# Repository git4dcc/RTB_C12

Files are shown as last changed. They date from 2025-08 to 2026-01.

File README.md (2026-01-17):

# RTB_C12





My homebrew RTB C12 Micro Booster implements a booster, DCC generator and Real-time Railcom detector. The booster is optimized for N-scale in respect to track voltage and current.

<details>
<summary>See also</summary>

- [RTB_C10 - Master](https://github.com/git4dcc/RTB_C10)
- [RTB_C11 - Power](https://github.com/git4dcc/RTB_C11)
- [RTB_C13 - Track Sensor](https://github.com/git4dcc/RTB_C13)
- [RTB_P15 - Base](https://github.com/git4dcc/RTB_P15)

</details>

<details>
<summary>User Guides</summary>

- User Guide - DE
- [User Guide - EN](https://rtb4dcc.de/rtb_user_guide_en/)

</details>

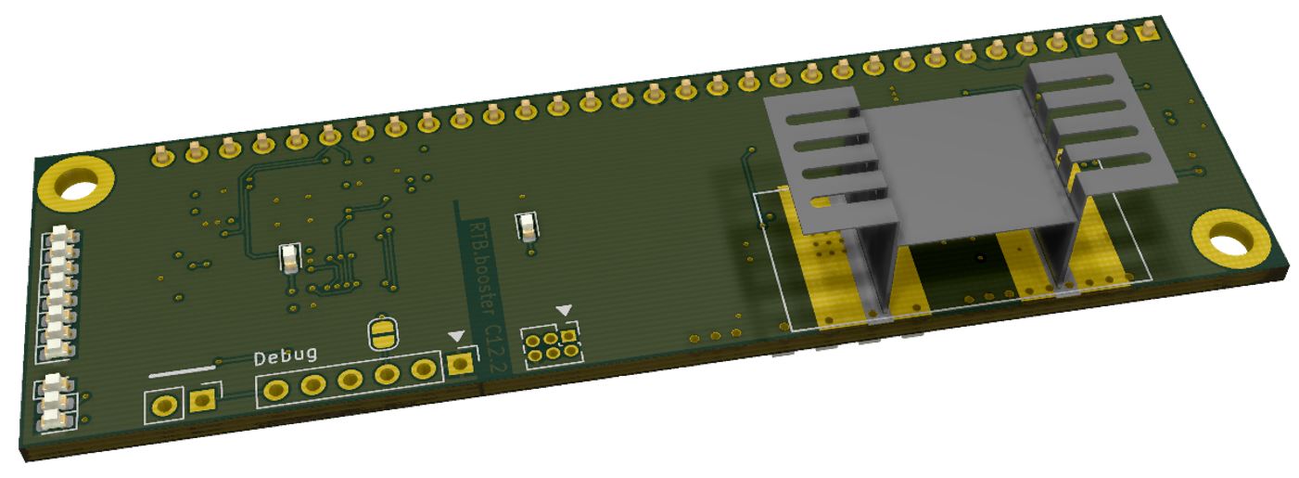
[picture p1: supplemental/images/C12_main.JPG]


## Booster features
- **FDX**
  - FDX bus (2Mbps full duplex)
- **DCC protocol generator**
  - unlimited decoder stack depth
  - DCC bandwidth monitor
  - DCC-A protocol (incl. stretched start bit)
  - DCC-R protocol (incl. update of RTB decoder on main)
- **MDU protocol generator**
  - Zimo MDU ([Multi Decoder Update](https://github.com/ZIMO-Elektronik/MDU))
  - update of MS and MN decoder
  - can update multiple MN/MS decoder concurrently
- **DECUP protocol generator**
  - Zimo DECUP ([**Dec**oder **Up**date](https://github.com/ZIMO-Elektronik/DECUP))
  - update of MX decoder
- **Booster**
  - Software programmable output voltage (3..18V)
  - 1A continuous current (1.5A peak)
  - Current limiter
  - Short circuit detection
  - Configurable bridge dead time (170ns..3500ns)
  - DCC signal timing adjustable [micro sec granularity]
  - Railcom Cutout timing adjustable
  - Up to 500kHz fast signaling
  - Voltage and current measurement
- **Railcom Detector**
  - channel 1 / channel 2
  - detects unlimited number of decoder
  - Railcom polarity detection
  - Railcom timing capture for decoder analysis
- **Service Mode**
  - read/write DCC decoder in “service mode”
  - ACK current detector adjustable
- **Firmware update over the bus**

# Hardware
The PCB layout uses SMD footprints with 0.4mm pitch and mostly 0603 parts. Reflow soldering is recommended, but with some experience handsoldering is also possible.
Further, the PCB has been optimized for automated assembly (BOM and Position files as CSV).

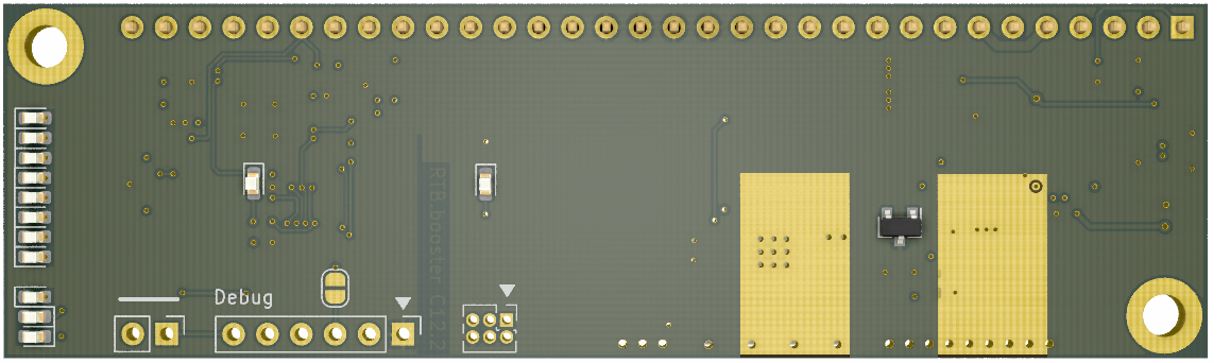
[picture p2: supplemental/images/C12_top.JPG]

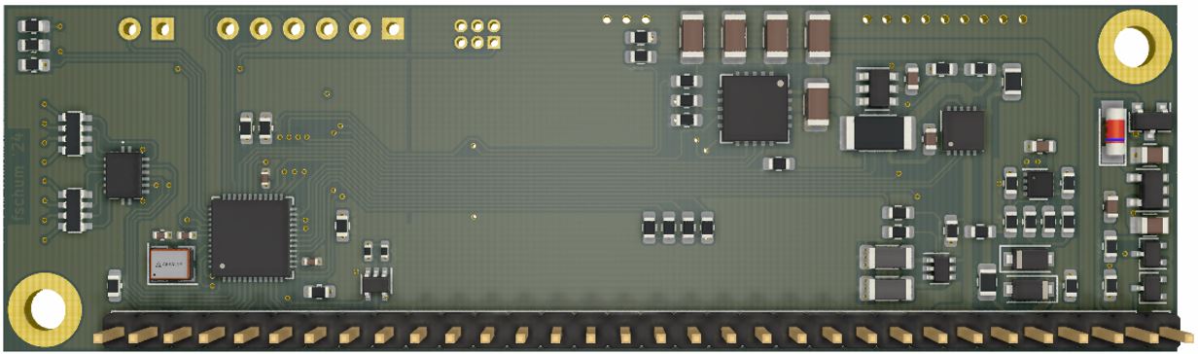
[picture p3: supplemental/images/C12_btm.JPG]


## PCB
- 4-layer PCB, FR4, 1.6mm
- CPU: AVR64DB48
- H-Bridge: BD63573NUV
- Voltage: OPA521

## Kicad
[Schematic](doc/C12_schematic.pdf) | [Layout](doc/C12_layout.pdf) | [Gerber](gerber)

# Firmware
Filename structure: { **pcb** }{ **code** }{ **version** }.hex

Example: **C12F0001**.hex

| | Description |
| --- | --- |
| **pcb** | Name of matching hardware (**C12**) |
| **code** | Type of code contained (**R**=rom, **B**=bootloader, **F**=flash, **U**=bld update, **P**=UPDI factory code) |
| **version** | Release version (**####**) |

[Firmware files](firmware)

## UPDI / Fuses
The fuse settings as well as the P-code (C12Pxxxx.hex) has to be installed by using UPDI.<br>

| Fuses Setting |
| --- |
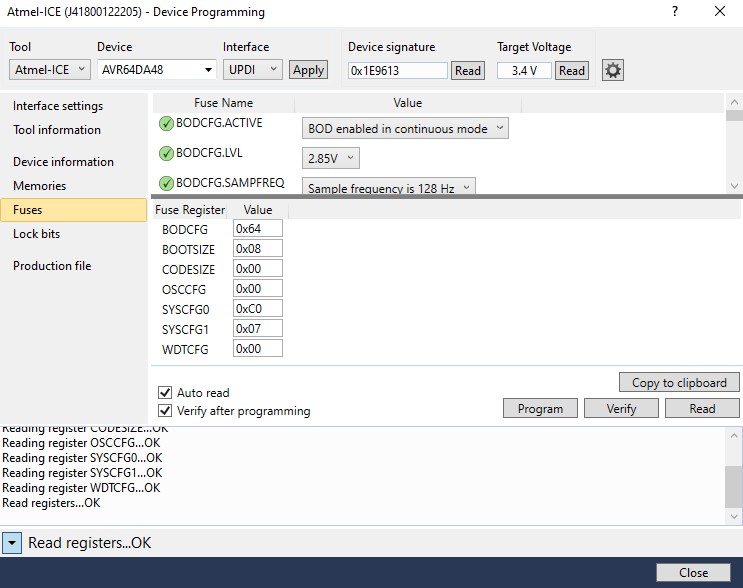
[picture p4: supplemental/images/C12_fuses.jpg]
||

# Images
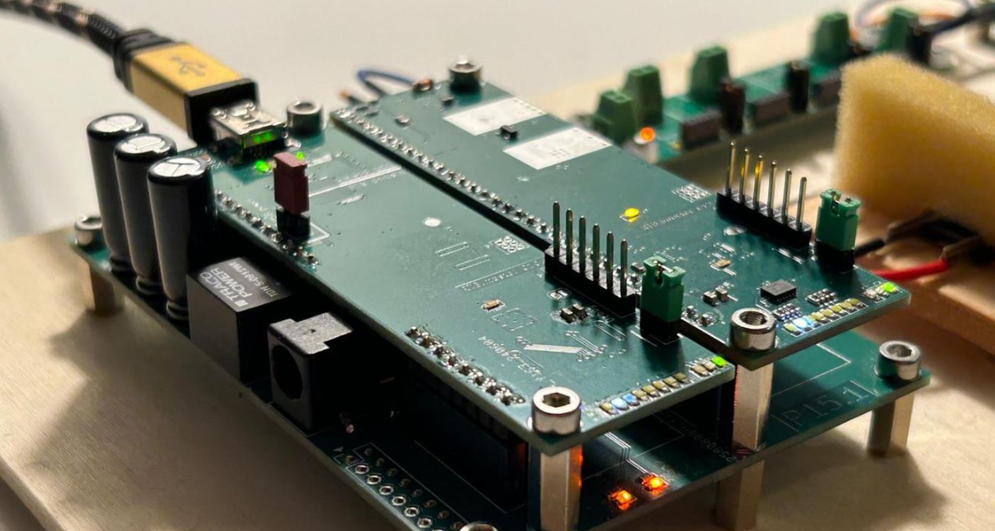
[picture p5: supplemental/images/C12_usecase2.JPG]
 

# YouTube
See the C12 booster in action.<br><br>
[](https://youtu.be/n1b2I9GNrNY)

This project is intended for hobby use only and is distributed in accordance with the Apache License 2.0 agreement.

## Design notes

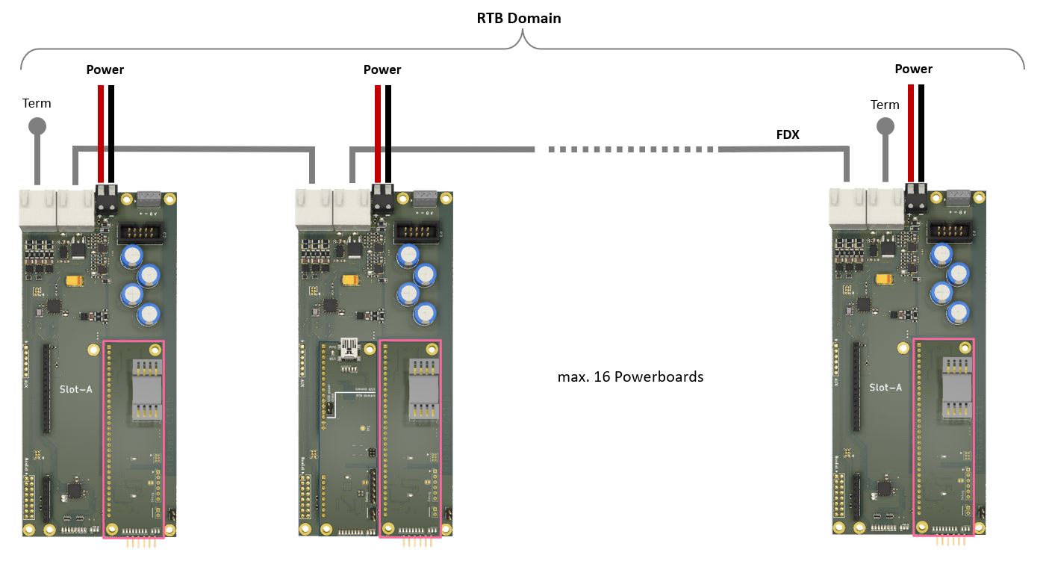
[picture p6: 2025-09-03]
supplemental/images/C12_usecase3.JPG

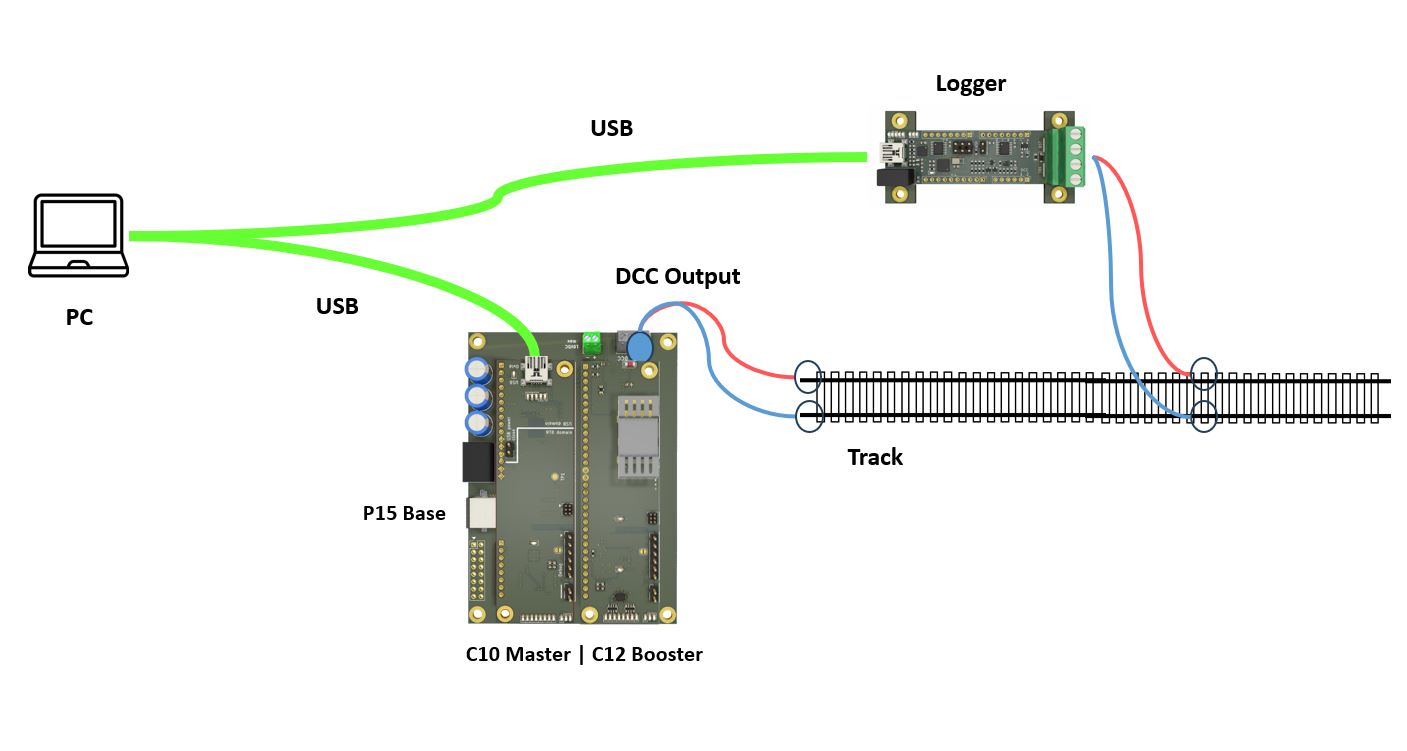
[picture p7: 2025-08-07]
supplemental/images/C12_usecase1.JPG

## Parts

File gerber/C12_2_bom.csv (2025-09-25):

Designator | Footprint | Quantity | Value | LCSC Part #
C1, C19, C4, C8, C9 | 1206 | 5 | 22uF | C12891
C10, C14, C15, C6 | 0402 | 4 | 100nF | C307331
C11, C20 | 0603 | 2 | 100nF | C14663
C2, C3 | 0805 | 2 | 10uF | C440198
C21, C5 | 0603 | 2 | 1uF | C15849
D12 | 0603 | 1 | Reset(red) | C2986060
D13 | 0603 | 1 | Msg(blu) | C434421
D14, D32, D33, D34, D35, D36, D37 | 0603 | 7 | LED_Small | C2290
D16 | 0603 | 1 | LED | C84264
D17 | D_MiniMELF | 1 | D_Schottky_Small | C81181
D3, D4 | SOT-323_SC-70 | 2 | BAT54S | C549280
D31 | SOT-323_SC-70 | 1 | BAT54C | C82467
D38 | 0603 | 1 | LED(wht) | C2290
D5 | 0603 | 1 | Hbt(grn) | C84264
D6, D9 | D_SOD-123F | 2 | SS34FA | C719833
D8 | 0603 | 1 | LED | C72038
H1, H3 | MountingHole_3.2mm_M3_ISO7380_Pad | 2 | MountingHole
IC1 | VSON-10-1EP_3x3mm_P0.5mm_EP1.2x2mm | 1 | BD63573NUV-E2 | C2150564
IC3 | DHVQFN-16-1EP_2.5x3.5mm_P0.5mm_EP1x2mm | 1 | 74HC595BQ,115 | C547123
J1 | PinHeader_1x06_P2.54mm_Vertical | 1 | Debug IF
J2 | PinHeader_1x32_P2.54mm_Vertical | 1 | Slot Connector
J3 | PinHeader_2x03_P1.27mm_Vertical | 1 | UPDI
JP1 | PinHeader_1x02_P2.54mm_Vertical | 1 | Jumper_2_Open
JP2 | SolderJumper-2_P1.3mm_Open_RoundedPad1.0x1.5mm | 1 | SolderJumper_2_Open
Q1 | SOT-363_SC-70-6 | 1 | BC847BDW1 | C82368
R1, R19 | 0402 | 2 | 3.3k | C25890
R10 | 0603 | 1 | 56k | C23206
R11 | 0603 | 1 | 33k | C4216
R12, R35 | 0603 | 2 | 10k | C25804
R13, R18, R27 | 0603 | 3 | 220k | C22961
R14, R21, R23 | 0603 | 3 | 9.1k | C23260
R17 | 2010 | 1 | 0.025 | C22470461
R2, R22 | 0603 | 2 | 100k | C25803
R20 | 0603 | 1 | 100 | C22775
R24, R25, R28, R30, R39 | 0603 | 5 | 3.3k | C22978
R26, R32 | 1206 | 2 | 300 | C17887
R29 | 0603 | 1 | 4.7k | C23162
R3, R33, R34, R4, R5, R6 | 0603 | 6 | 1k | C21190
R31 | 0805 | 1 | 10k | C17414
R36, R37, R38 | 0603 | 3 | 22k | C31850
R7, R8 | 0603 | 2 | 82k | C23254
R9 | 0805 | 1 | 22 | C17561
RN3, RN4 | R_Array_Convex_4x0603 | 2 | 4.7k | C1980
U1 | SOT-353_SC-70-5 | 1 | 74AHC1G08 | C12490
U15 | SOT-23 | 1 | MCP9700AT-ETT | C127949
U3 | SOT-23-6 | 1 | INA181A1 | C2058943
U4 | DFN-8-1EP_NG_2x2mm_Pitch0.5mm | 1 | LM393 | C2970927
U5 | SOT-23-5 | 1 | MIC5235-3.3 | C89886
U6 | QFN-48-1EP_6x6mm_P0.4mm_EP4.2x4.2mm | 1 | AVR64DA48 | C3227399
U8 | QFN-20-1EP_5x5mm_P0.65mm_EP3.35x3.35mm | 1 | OPA521 | C2058423
X1 | Oscillator_SMD_Abracon_ASE-4Pin_3.2x2.5mm | 1 | ASE-24MHz | C1987527

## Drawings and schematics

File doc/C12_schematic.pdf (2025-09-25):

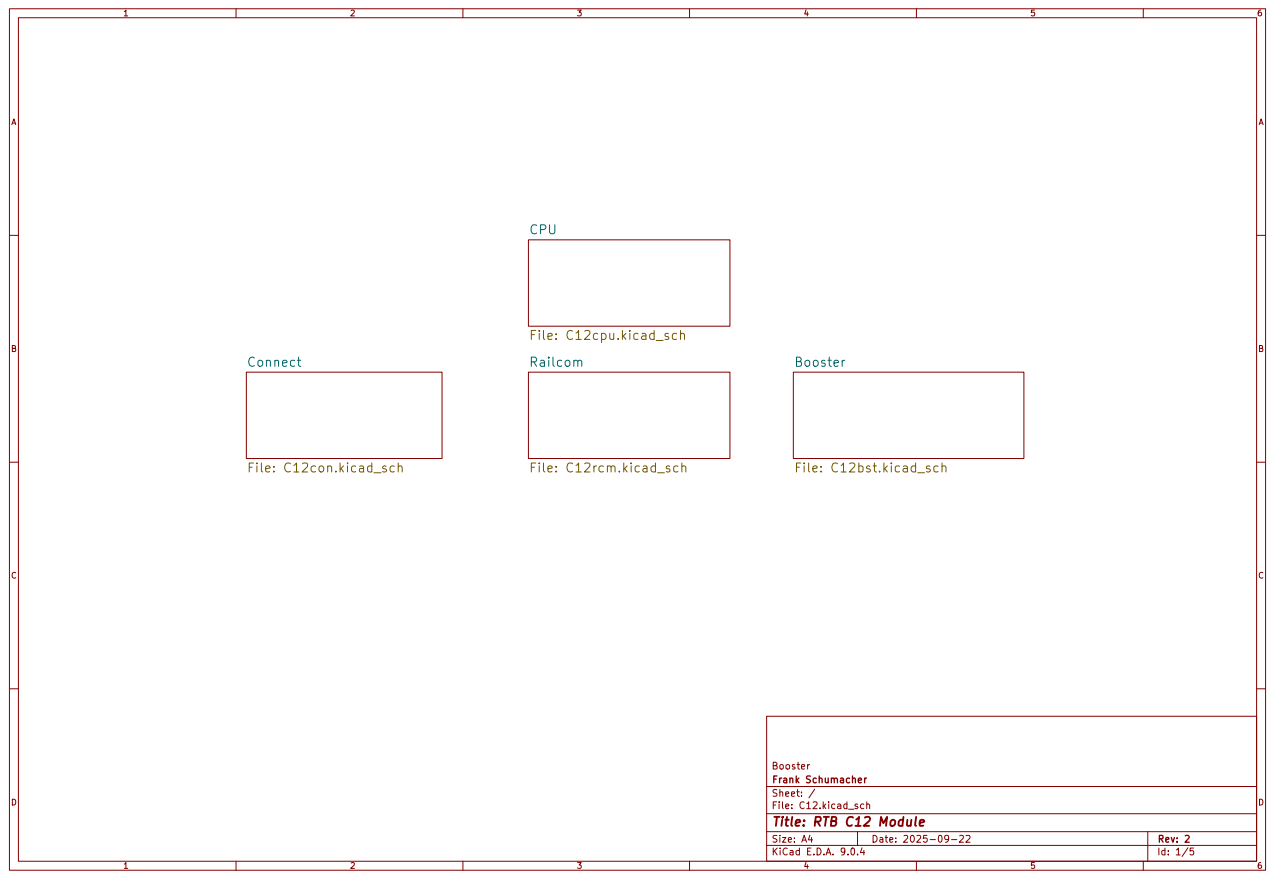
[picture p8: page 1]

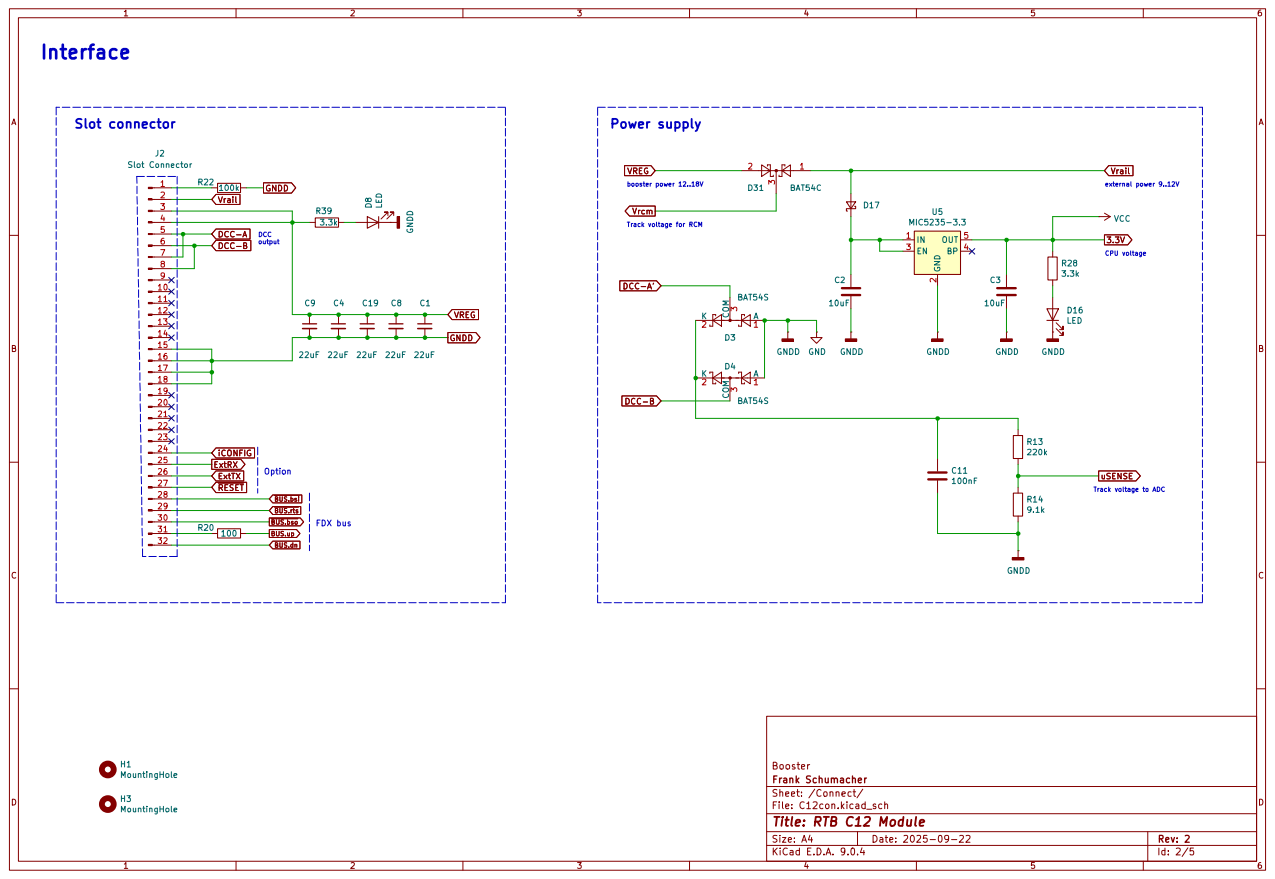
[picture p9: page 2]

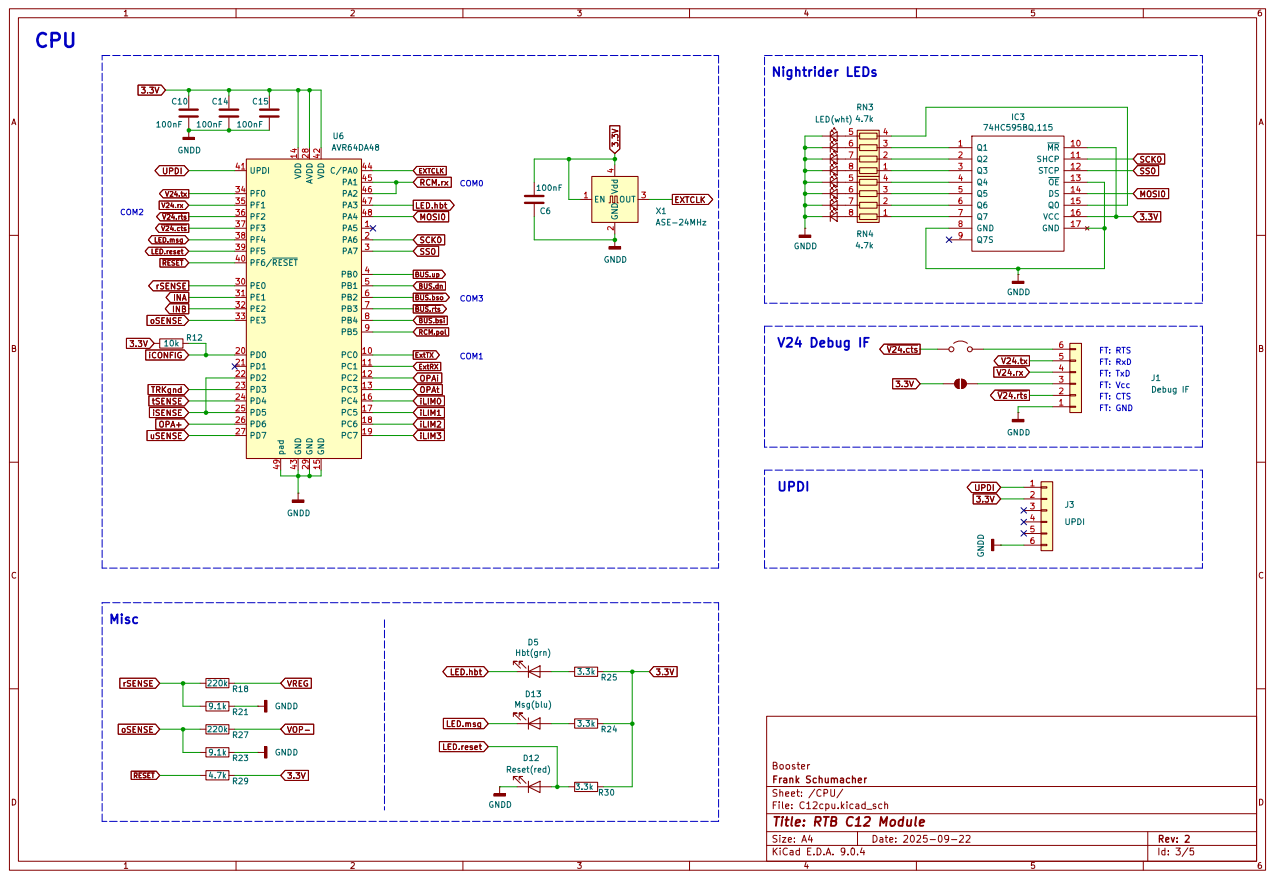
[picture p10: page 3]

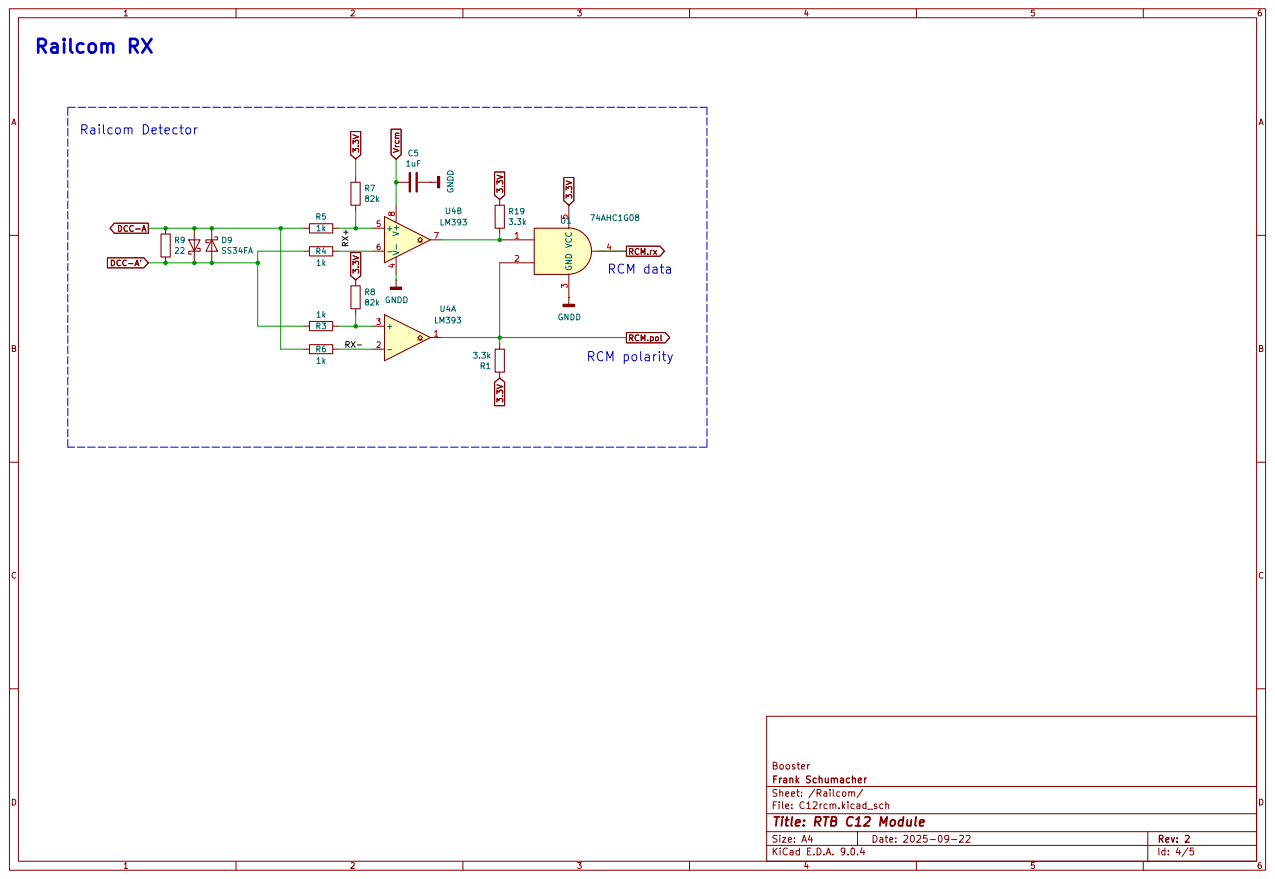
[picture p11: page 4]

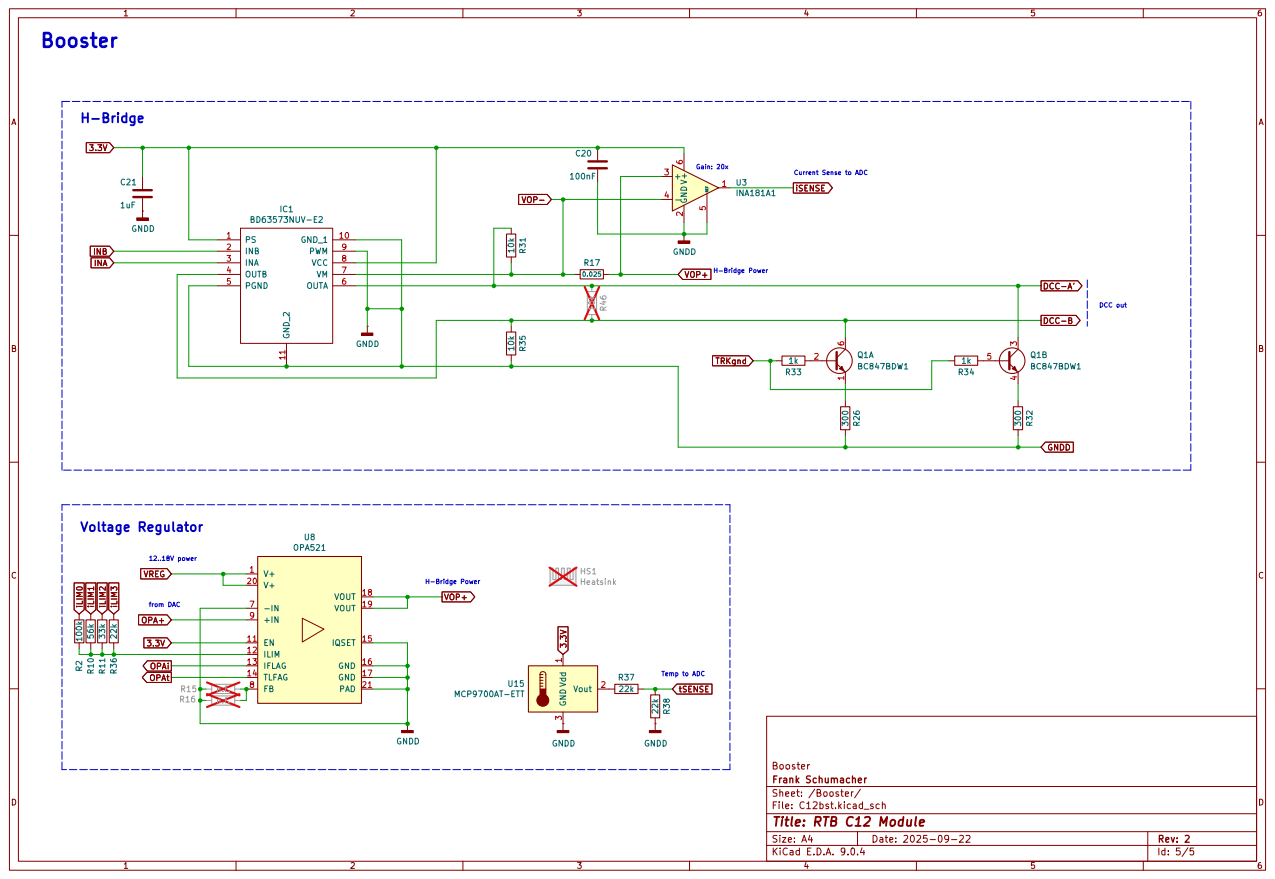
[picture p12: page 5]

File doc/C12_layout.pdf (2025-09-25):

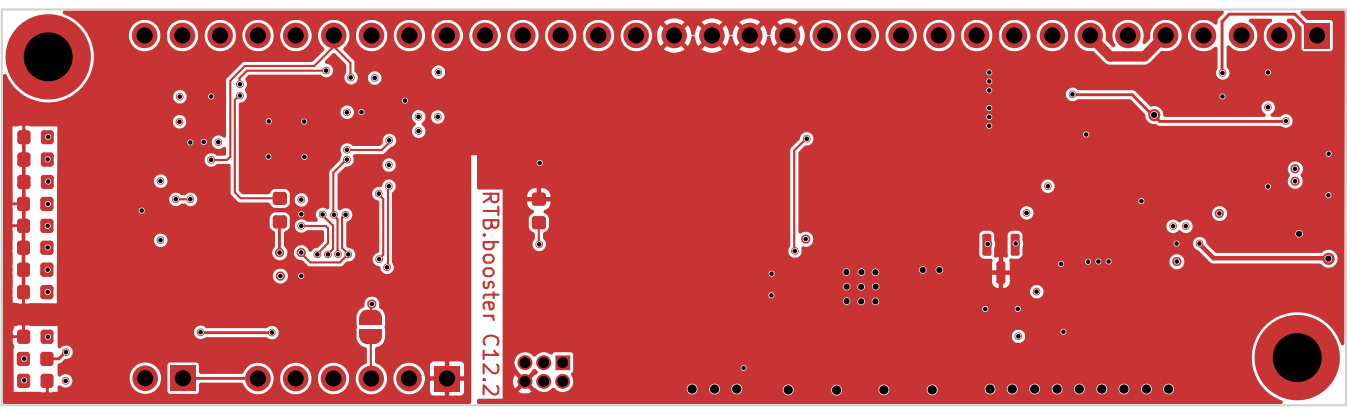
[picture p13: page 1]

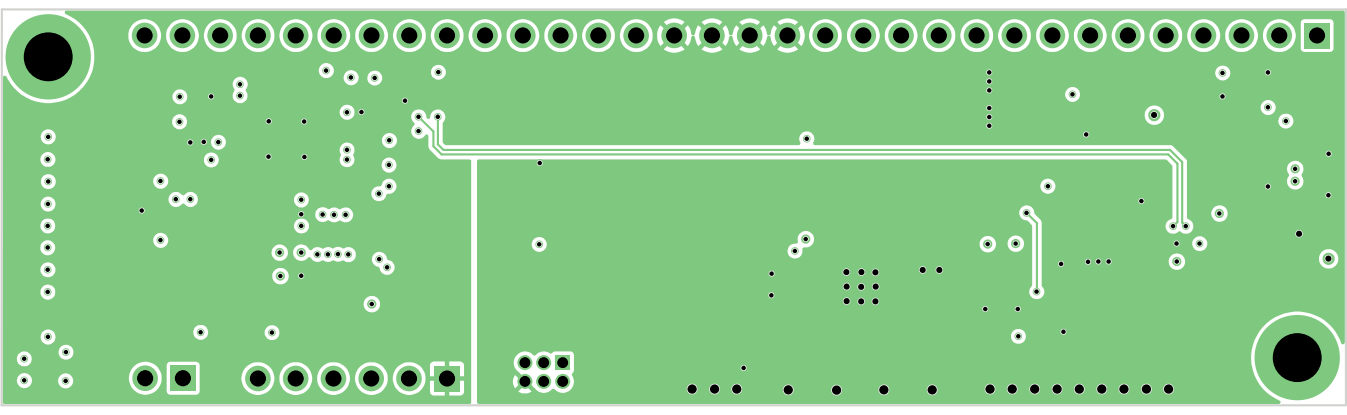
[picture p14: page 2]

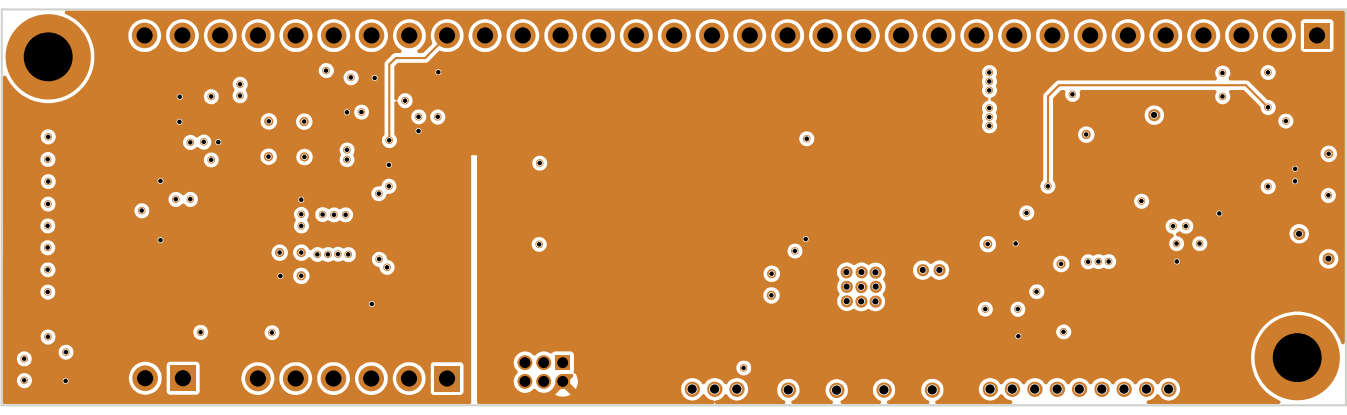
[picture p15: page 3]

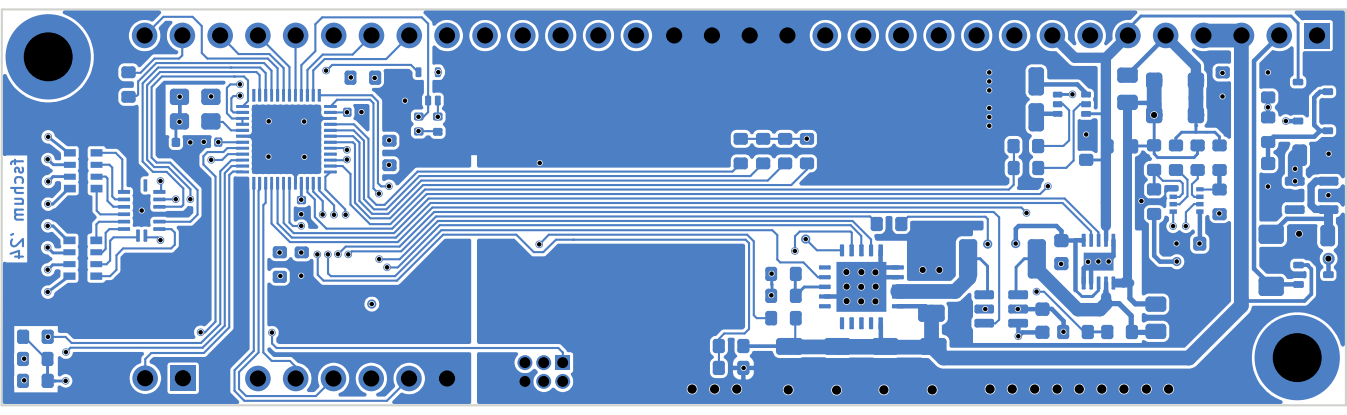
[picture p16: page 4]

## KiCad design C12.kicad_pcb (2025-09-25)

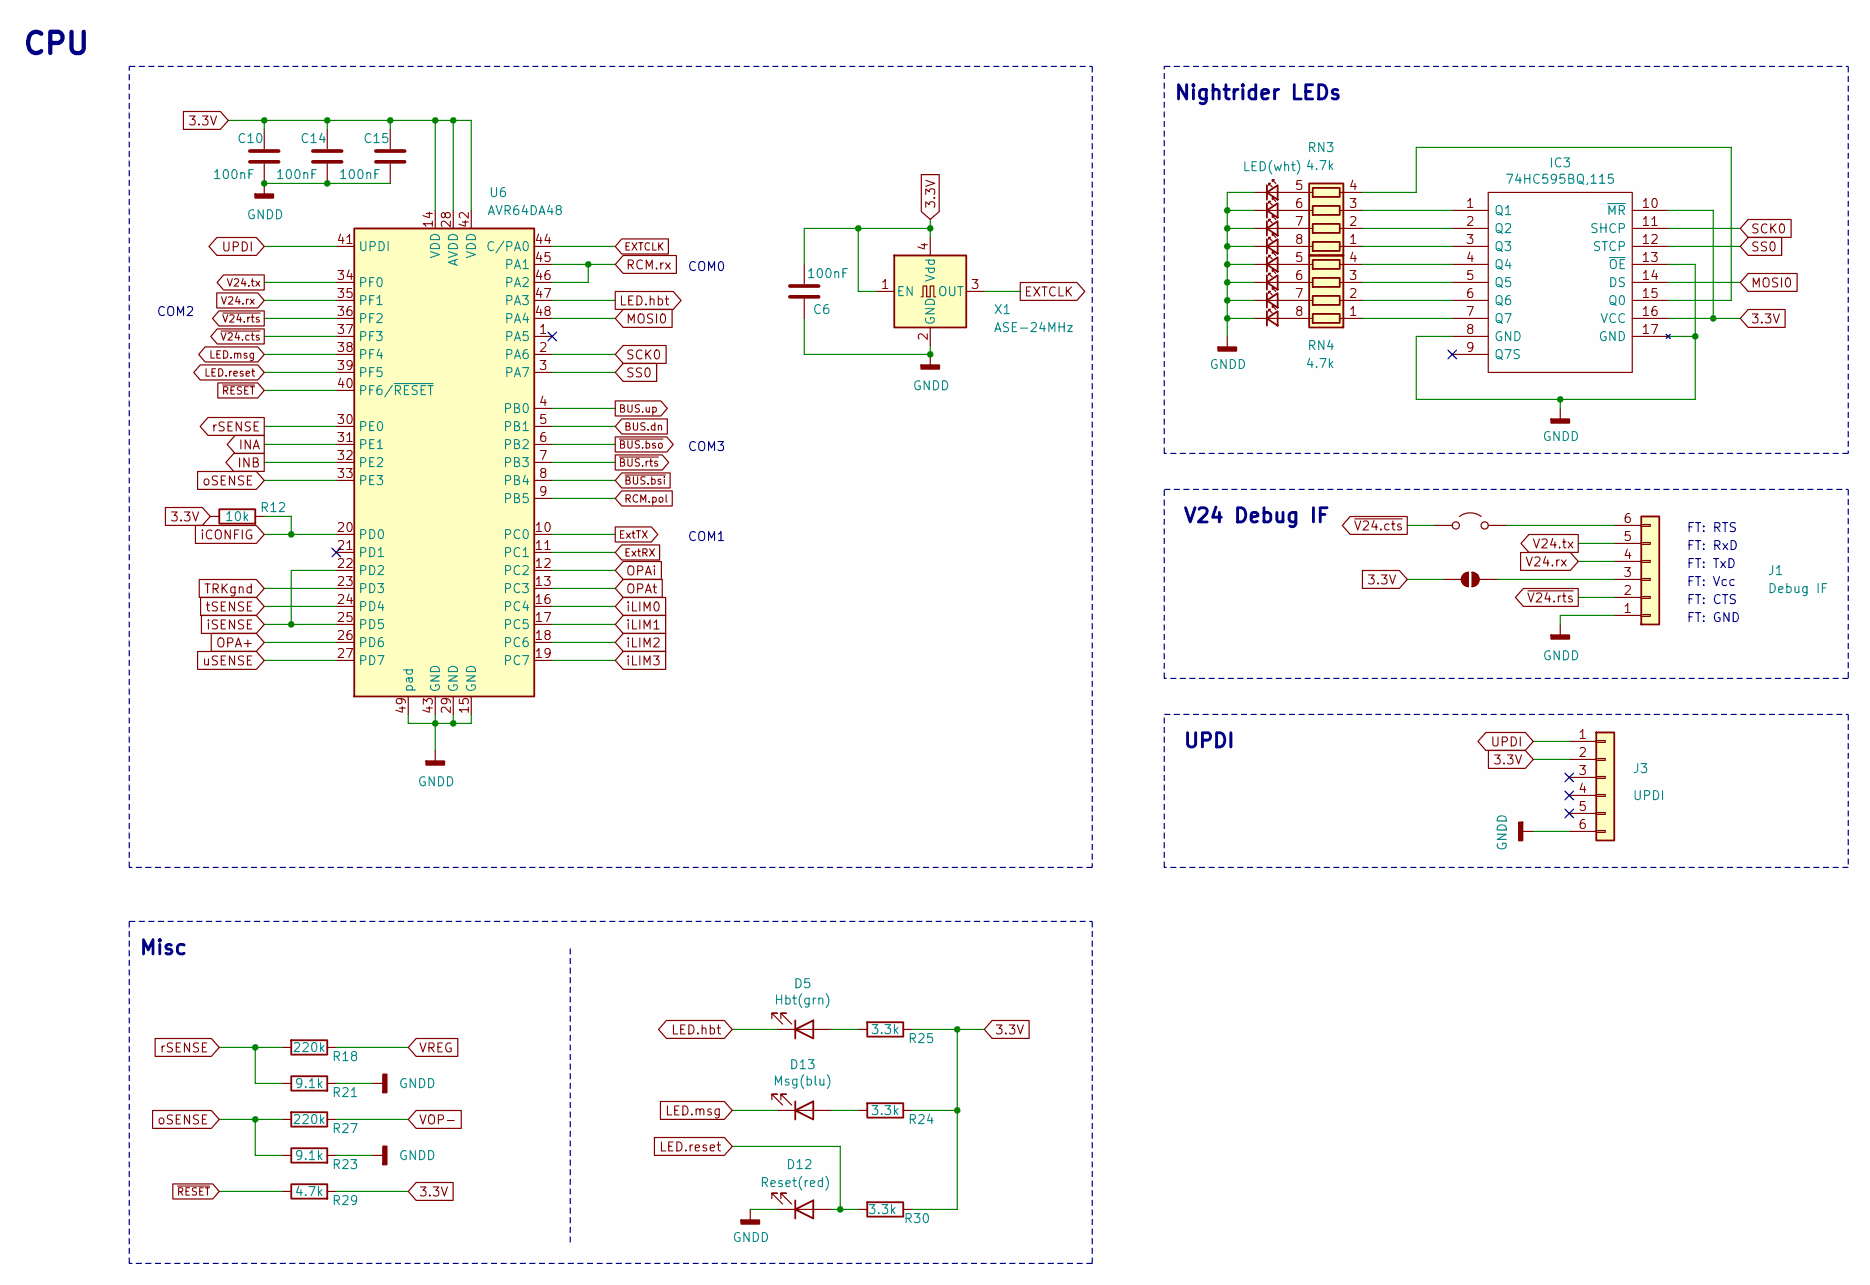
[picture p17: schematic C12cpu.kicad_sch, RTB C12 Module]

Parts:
C6, C10, C14, C15: 100nF; C_0402_1005Metric; LCSC Part # C307331
D5: Hbt(grn); LED_0603_1608Metric; LCSC Part # C84264
D12: Reset(red); LED_0603_1608Metric; LCSC Part # C2986060
D13: Msg(blu); LED_0603_1608Metric; LCSC Part # C434421
D14, D32, D33, D34, D35, D36, D37: LED_Small; LED_0603_1608Metric; LCSC Part # C2290
D38: LED(wht); LED_0603_1608Metric; LCSC Part # C2290
IC3: 74HC595BQ,115; DHVQFN-16-1EP_2.5x3.5mm_P0.5mm_EP1x2mm; LCSC Part # C547123
J1: Debug IF; PinHeader_1x06_P2.54mm_Vertical
J3: UPDI; PinHeader_2x03_P1.27mm_Vertical
JP1: Jumper_2_Open; PinHeader_1x02_P2.54mm_Vertical
JP2: SolderJumper_2_Open; SolderJumper-2_P1.3mm_Open_RoundedPad1.0x1.5mm
R12: 10k; R_0603_1608Metric; LCSC Part # C25804
R18, R27: 220k; R_0603_1608Metric; LCSC Part # C22961
R21, R23: 9.1k; R_0603_1608Metric; LCSC Part # C23260
R24, R25, R30: 3.3k; R_0603_1608Metric; LCSC Part # C22978
R29: 4.7k; R_0603_1608Metric; LCSC Part # C23162
RN3, RN4: 4.7k; R_Array_Convex_4x0603; LCSC Part # C1980
U6: AVR64DA48; QFN-48-1EP_6x6mm_P0.4mm_EP4.2x4.2mm; LCSC Part # C3227399
X1: ASE-24MHz; Oscillator_SMD_Abracon_ASE-4Pin_3.2x2.5mm; LCSC Part # C1987527

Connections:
3.3V: C6.1, C10.1, C14.1, C15.1, IC3.10 (~MR), IC3.16 (VCC), J3.2, JP2.1 (A), R12.1, R24.1, R25.1, R29.2, R30.1, U6.14 (VDD), U6.28 (AVDD), U6.42 (VDD), X1.1 (EN), X1.4 (Vdd); also elsewhere on the board
BUS.dn: U6.5 (PB1); also elsewhere on the board
BUS.up: U6.4 (PB0); also elsewhere on the board
EXTCLK: U6.44 (C/PA0), X1.3 (OUT)
ExtRX: U6.11 (PC1); also elsewhere on the board
ExtTX: U6.10 (PC0); also elsewhere on the board
GNDD: C6.2, C10.2, C14.2, C15.2, D12.1 (K), D14.1 (K), D32.1 (K), D33.1 (K), D34.1 (K), D35.1 (K), D36.1 (K), D37.1 (K), D38.1 (K), IC3.8 (GND), IC3.13 (~OE), IC3.17 (GND), J1.1, J3.6, R21.2, R23.2, U6.15 (GND), U6.29 (GND), U6.43 (GND), U6.49 (GND), X1.2 (GND); also elsewhere on the board
INA: U6.31 (PE1); also elsewhere on the board
INB: U6.32 (PE2); also elsewhere on the board
LED.hbt: D5.1 (K), U6.47 (PA3)
LED.msg: D13.1 (K), U6.38 (PF4)
LED.reset: D12.2 (A), R30.2, U6.39 (PF5)
MOSI0: IC3.14 (DS), U6.48 (PA4)
unnamed: D5.2 (A), R25.2
unnamed: D13.2 (A), R24.2
unnamed: D14.2 (A), RN4.8 (R1.2)
unnamed: D32.2 (A), RN4.7 (R2.2)
unnamed: D33.2 (A), RN4.6 (R3.2)
unnamed: D34.2 (A), RN4.5 (R4.2)
unnamed: D35.2 (A), RN3.8 (R1.2)
unnamed: D36.2 (A), RN3.7 (R2.2)
unnamed: D37.2 (A), RN3.6 (R3.2)
unnamed: D38.2 (A), RN3.5 (R4.2)
unnamed: IC3.15 (Q0), RN3.4 (R4.1)
unnamed: IC3.1 (Q1), RN3.3 (R3.1)
unnamed: IC3.2 (Q2), RN3.2 (R2.1)
unnamed: IC3.3 (Q3), RN3.1 (R1.1)
unnamed: IC3.4 (Q4), RN4.4 (R4.1)
unnamed: IC3.5 (Q5), RN4.3 (R3.1)
unnamed: IC3.6 (Q6), RN4.2 (R2.1)
unnamed: IC3.7 (Q7), RN4.1 (R1.1)
unnamed: J1.3, JP2.2 (B)
unnamed: J1.6, JP1.1 (A)
OPA+: U6.26 (PD6); also elsewhere on the board
OPAi: U6.12 (PC2); also elsewhere on the board
OPAt: U6.13 (PC3); also elsewhere on the board
RCM.pol: U6.9 (PB5); also elsewhere on the board
RCM.rx: U6.45 (PA1), U6.46 (PA2); also elsewhere on the board
SCK0: IC3.11 (SHCP), U6.2 (PA6)
SS0: IC3.12 (STCP), U6.3 (PA7)
TRKgnd: U6.23 (PD3); also elsewhere on the board
UPDI: J3.1, U6.41 (UPDI)
V24.rx: J1.4, U6.35 (PF1)
V24.tx: J1.5, U6.34 (PF0)
VOP-: R27.1; also elsewhere on the board
VREG: R18.1; also elsewhere on the board
iCONFIG: R12.2, U6.20 (PD0); also elsewhere on the board
iLIM0: U6.16 (PC4); also elsewhere on the board
iLIM1: U6.17 (PC5); also elsewhere on the board
iLIM2: U6.18 (PC6); also elsewhere on the board
iLIM3: U6.19 (PC7); also elsewhere on the board
iSENSE: U6.22 (PD2), U6.25 (PD5); also elsewhere on the board
oSENSE: R23.1, R27.2, U6.33 (PE3)
rSENSE: R18.2, R21.1, U6.30 (PE0)
tSENSE: U6.24 (PD4); also elsewhere on the board
uSENSE: U6.27 (PD7); also elsewhere on the board
~BUS.bsi: U6.8 (PB4); also elsewhere on the board
~BUS.bso: U6.6 (PB2); also elsewhere on the board
~BUS.rts: U6.7 (PB3); also elsewhere on the board
~RESET: R29.1, U6.40 (PF6/~RESET); also elsewhere on the board
~V24.cts: JP1.2 (B), U6.37 (PF3)
~V24.rts: J1.2, U6.36 (PF2)

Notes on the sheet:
FT: GND
Misc
COM0
COM1
UPDI
Nightrider LEDs
FT: RTS
FT: Vcc
FT: CTS
FT: RxD
COM2
COM3
FT: TxD
CPU
V24 Debug IF

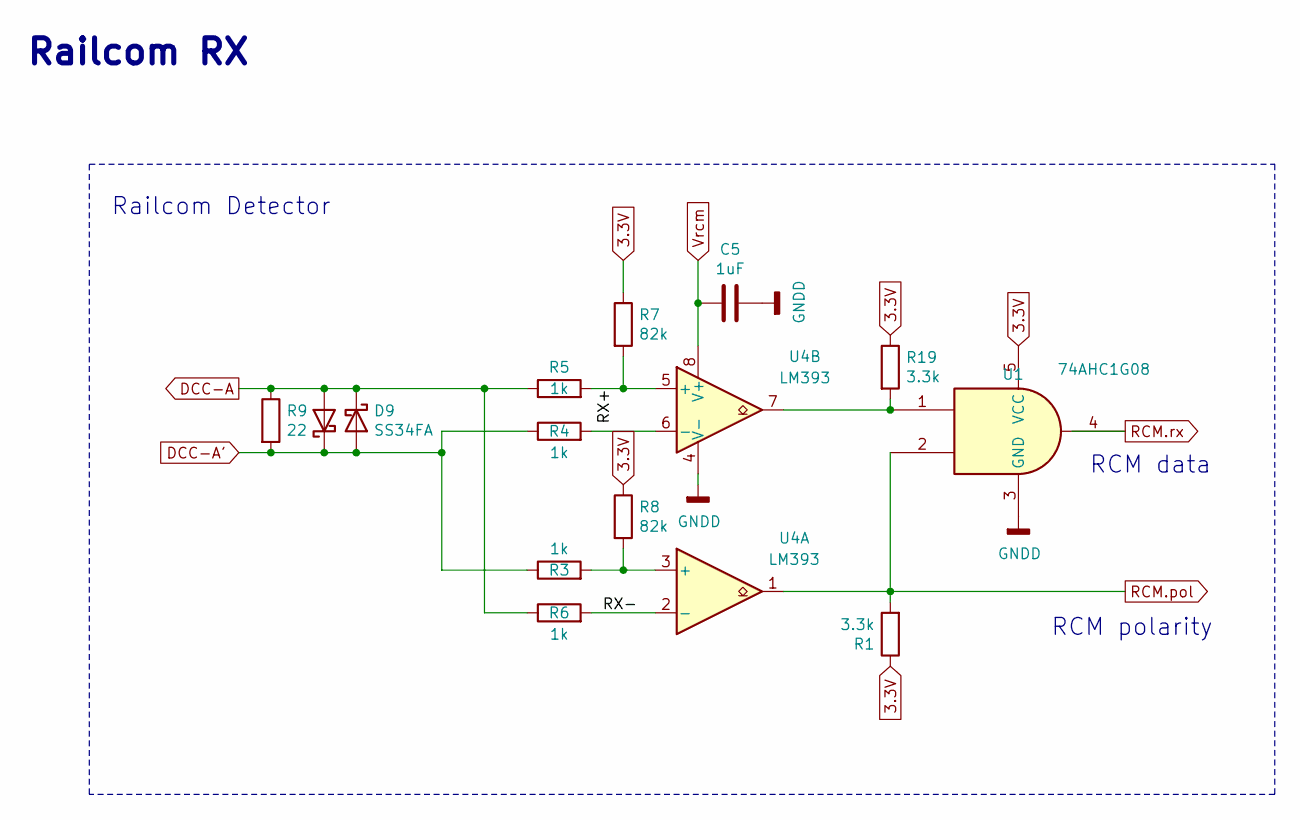
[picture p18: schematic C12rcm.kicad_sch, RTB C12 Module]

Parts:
C5: 1uF; C_0603_1608Metric; LCSC Part # C15849
D6, D9: SS34FA; D_SOD-123F; LCSC Part # C719833
R1, R19: 3.3k; R_0402_1005Metric; LCSC Part # C25890
R3, R4, R5, R6: 1k; R_0603_1608Metric; LCSC Part # C21190
R7, R8: 82k; R_0603_1608Metric; LCSC Part # C23254
R9: 22; R_0805_2012Metric; LCSC Part # C17561
U1: 74AHC1G08; SOT-353_SC-70-5; LCSC Part # C12490
U4: LM393; DFN-8-1EP_NG_2x2mm_Pitch0.5mm; LCSC Part # C2970927

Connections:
3.3V: R1.1, R7.1, R8.1, R19.1, U1.5 (VCC); also elsewhere on the board
/Railcom/RX+: R5.2, R7.2, U4.5 (+)
/Railcom/RX-: R6.2, U4.2 (-)
DCC-A: D6.2 (A), D9.1 (K), R5.1, R6.1, R9.1; also elsewhere on the board
DCC-A': D6.1 (K), D9.2 (A), R3.1, R4.1, R9.2; also elsewhere on the board
GNDD: C5.1, U1.3 (GND), U4.4 (V-); also elsewhere on the board
unnamed: R19.2, U1.1, U4.7
unnamed: R3.2, R8.2, U4.3 (+)
unnamed: R4.2, U4.6 (-)
RCM.pol: R1.2, U1.2, U4.1; also elsewhere on the board
RCM.rx: U1.4; also elsewhere on the board
Vrcm: C5.2, U4.8 (V+); also elsewhere on the board

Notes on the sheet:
Railcom Detector
Railcom RX
RCM polarity
RCM data

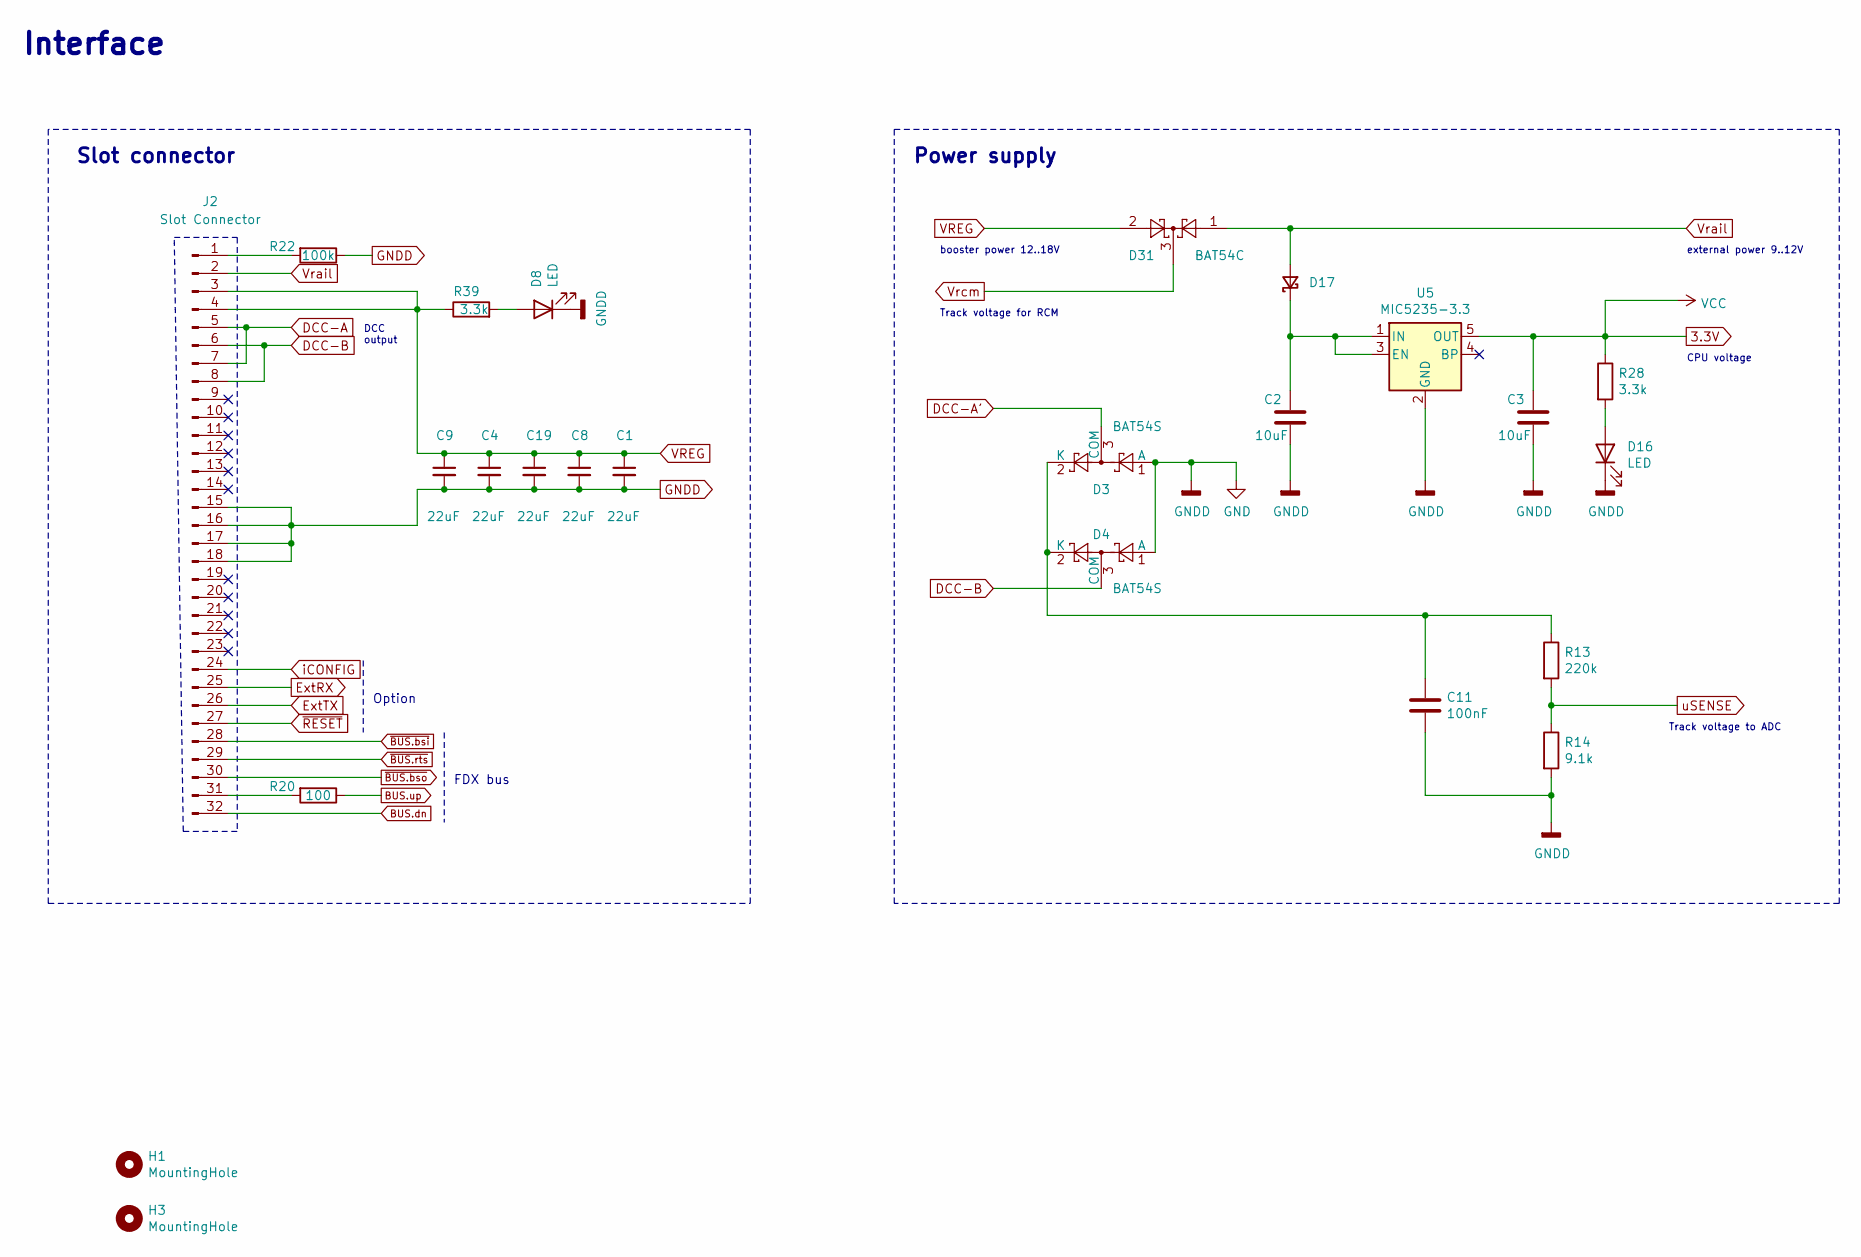
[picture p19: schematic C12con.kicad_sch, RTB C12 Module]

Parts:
C1, C4, C8, C9, C19: 22uF; C_1206_3216Metric; LCSC Part # C12891
C2, C3: 10uF; C_0805_2012Metric; LCSC Part # C440198
C11: 100nF; C_0603_1608Metric; LCSC Part # C14663
D3, D4: BAT54S; SOT-323_SC-70; LCSC Part # C549280
D8: LED; LED_0603_1608Metric; LCSC Part # C72038
D16: LED; LED_0603_1608Metric; LCSC Part # C84264
D17: D_Schottky_Small; D_MiniMELF; LCSC Part # C81181
D31: BAT54C; SOT-323_SC-70; LCSC Part # C82467
H1, H3: MountingHole; MountingHole_3.2mm_M3_ISO7380_Pad
J2: Slot Connector; PinHeader_1x32_P2.54mm_Vertical
R13: 220k; R_0603_1608Metric; LCSC Part # C22961
R14: 9.1k; R_0603_1608Metric; LCSC Part # C23260
R20: 100; R_0603_1608Metric; LCSC Part # C22775
R22: 100k; R_0603_1608Metric; LCSC Part # C25803
R28, R39: 3.3k; R_0603_1608Metric; LCSC Part # C22978
U5: MIC5235-3.3; SOT-23-5; LCSC Part # C89886

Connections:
3.3V: C3.1, R28.1, U5.5 (OUT); also elsewhere on the board
BUS.dn: J2.32; also elsewhere on the board
BUS.up: R20.1; also elsewhere on the board
DCC-A: J2.5, J2.7; also elsewhere on the board
DCC-A': D3.3 (COM); also elsewhere on the board
DCC-B: D4.3 (COM), J2.6, J2.8; also elsewhere on the board
ExtRX: J2.25; also elsewhere on the board
ExtTX: J2.26; also elsewhere on the board
GNDD: C1.2, C2.2, C3.2, C4.2, C8.2, C9.2, C11.2, C19.2, D3.1 (A), D4.1 (A), D8.1 (K), D16.1 (K), J2.15, J2.16, J2.17, J2.18, R14.2, R22.1, U5.2 (GND); also elsewhere on the board
unnamed: C11.1, D3.2 (K), D4.2 (K), R13.1
unnamed: D8.2 (A), R39.2
unnamed: D16.2 (A), R28.2
unnamed: C2.1, D17.1 (K), U5.1 (IN), U5.3 (EN)
unnamed: J2.1, R22.2
unnamed: J2.31, R20.2
VREG: C1.1, C4.1, C8.1, C9.1, C19.1, D31.2, J2.3, J2.4, R39.1; also elsewhere on the board
Vrail: D17.2 (A), D31.1, J2.2
Vrcm: D31.3; also elsewhere on the board
iCONFIG: J2.24; also elsewhere on the board
uSENSE: R13.2, R14.1; also elsewhere on the board
~BUS.bsi: J2.28; also elsewhere on the board
~BUS.bso: J2.30; also elsewhere on the board
~BUS.rts: J2.29; also elsewhere on the board
~RESET: J2.27; also elsewhere on the board

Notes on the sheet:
booster power 12..18V
FDX bus
Track voltage for RCM
Slot connector
Interface
CPU voltage
Track voltage to ADC
Power supply
DCC output
Option
external power 9..12V

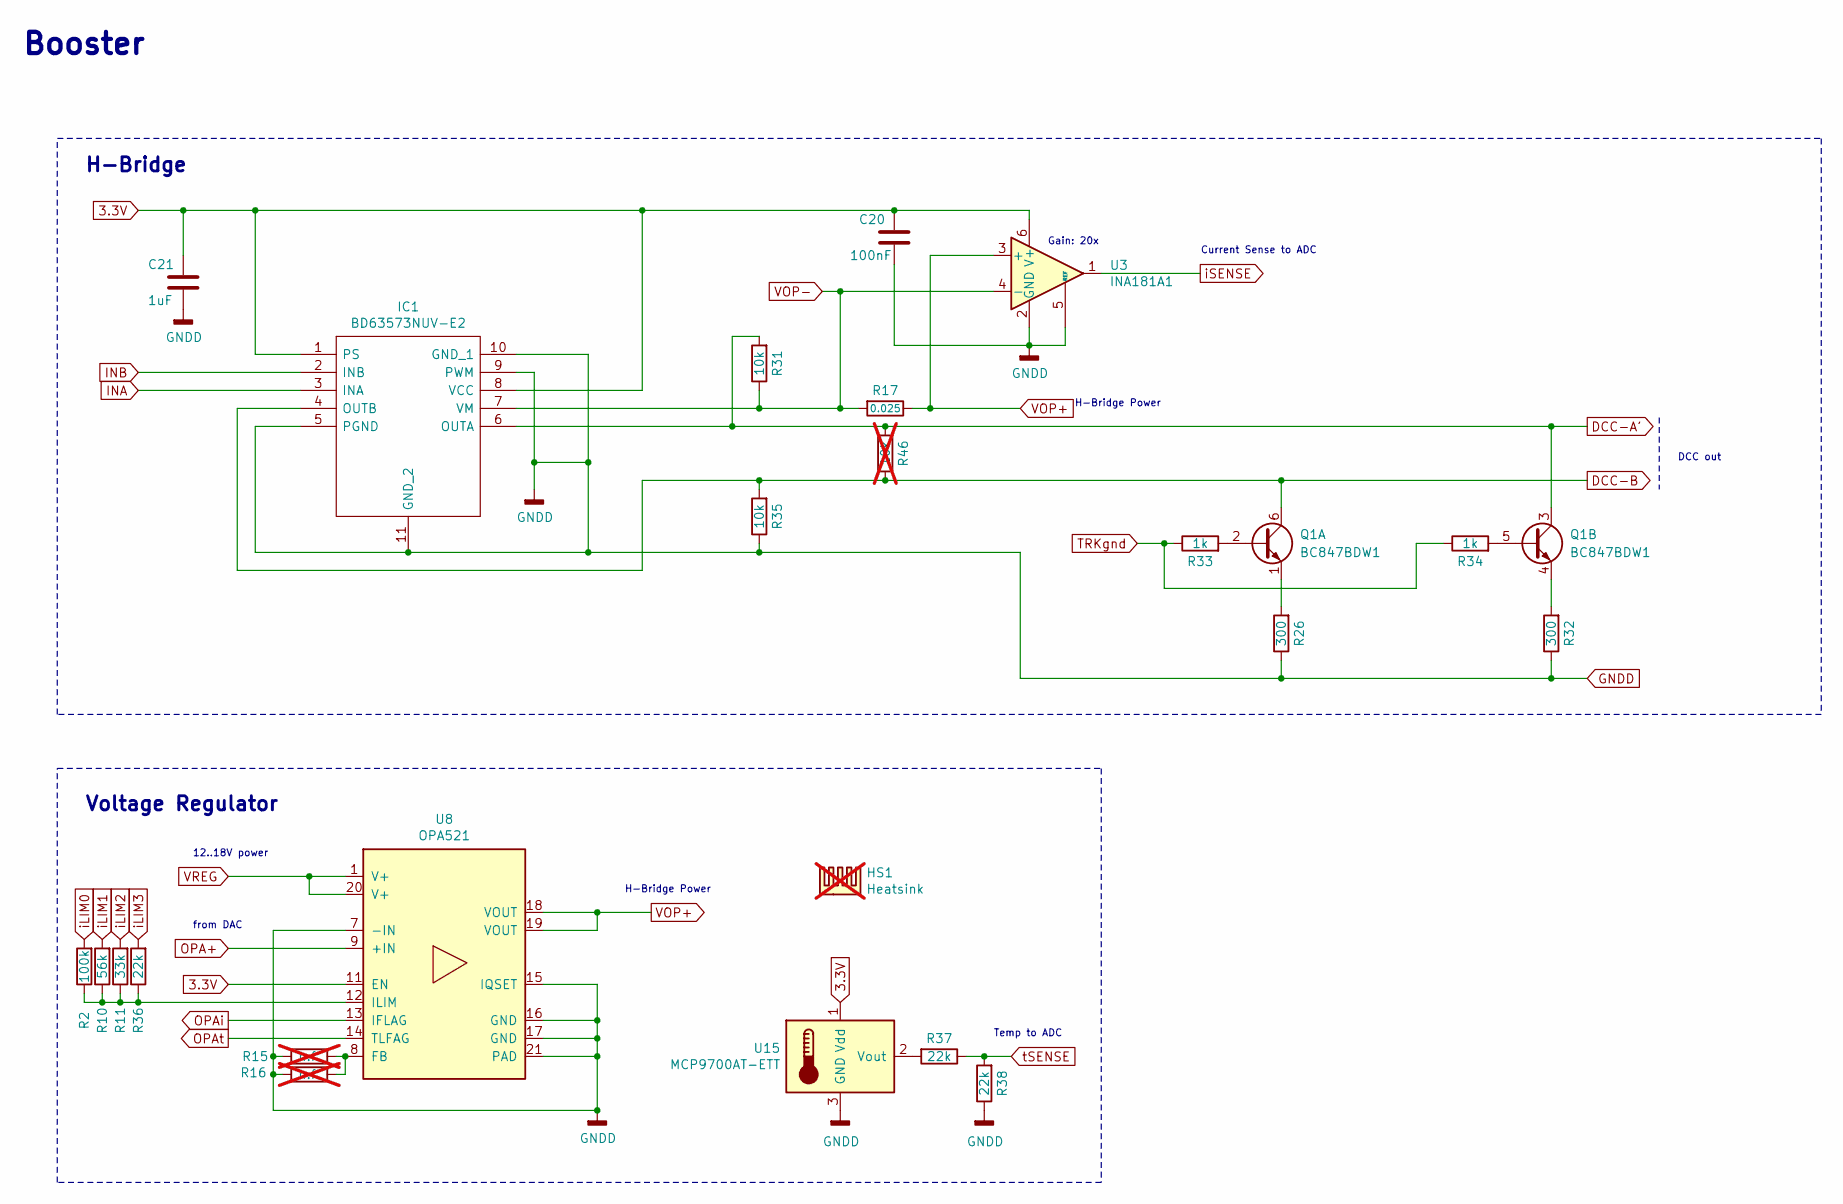
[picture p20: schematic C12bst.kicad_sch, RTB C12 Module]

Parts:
C20: 100nF; C_0603_1608Metric; LCSC Part # C14663
C21: 1uF; C_0603_1608Metric; LCSC Part # C15849
HS1: Heatsink; Heatsink_AAVID_573300D00010G_TO-263; not fitted
IC1: BD63573NUV-E2; VSON-10-1EP_3x3mm_P0.5mm_EP1.2x2mm; LCSC Part # C2150564
Q1: BC847BDW1; SOT-363_SC-70-6; LCSC Part # C82368
R2: 100k; R_0603_1608Metric; LCSC Part # C25803
R10: 56k; R_0603_1608Metric; LCSC Part # C23206
R11: 33k; R_0603_1608Metric; LCSC Part # C4216
R15, R16: n.f.; R_0603_1608Metric; not fitted
R17: 0.025; R_2010_5025Metric; LCSC Part # C22470461
R26, R32: 300; L_1206_3216Metric; LCSC Part # C17887
R31: 10k; R_0805_2012Metric; LCSC Part # C17414
R33, R34: 1k; R_0603_1608Metric; LCSC Part # C21190
R35: 10k; R_0603_1608Metric; LCSC Part # C25804
R36, R37, R38: 22k; R_0603_1608Metric; LCSC Part # C31850
R46: 10k; R_0603_1608Metric; LCSC Part # C25804; not fitted
U3: INA181A1; SOT-23-6; LCSC Part # C2058943
U8: OPA521; QFN-20-1EP_5x5mm_P0.65mm_EP3.35x3.35mm; LCSC Part # C2058423
U15: MCP9700AT-ETT; SOT-23; LCSC Part # C127949

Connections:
3.3V: C20.1, C21.1, IC1.1 (PS), IC1.8 (VCC), U3.6 (V+), U8.11 (EN), U15.1 (Vdd); also elsewhere on the board
DCC-A': IC1.6 (OUTA), Q1.3 (C2), R31.2, R46.2; also elsewhere on the board
DCC-B: IC1.4 (OUTB), Q1.6 (C1), R35.2, R46.1; also elsewhere on the board
GNDD: C20.2, C21.2, IC1.5 (PGND), IC1.9 (PWM), IC1.10 (GND_1), IC1.11 (GND_2), R15.2, R16.2, R26.1, R32.1, R35.1, R38.1, U3.2 (GND), U3.5 (REF), U8.7 (-IN), U8.15 (IQSET), U8.16 (GND), U8.17 (GND), U8.21 (PAD), U15.3 (GND); also elsewhere on the board
INA: IC1.3 (INA); also elsewhere on the board
INB: IC1.2 (INB); also elsewhere on the board
unnamed: Q1.2 (B1), R33.2
unnamed: Q1.1 (E1), R26.2
unnamed: Q1.5 (B2), R34.2
unnamed: Q1.4 (E2), R32.2
unnamed: R15.1, R16.1, U8.8 (FB)
unnamed: R2.1, R10.1, R11.1, R36.1, U8.12 (ILIM)
unnamed: R37.2, U15.2 (Vout)
OPA+: U8.9 (+IN); also elsewhere on the board
OPAi: U8.13 (IFLAG); also elsewhere on the board
OPAt: U8.14 (TLFAG); also elsewhere on the board
TRKgnd: R33.1, R34.1; also elsewhere on the board
VOP+: R17.1, U3.3 (+), U8.18 (VOUT), U8.19 (VOUT)
VOP-: IC1.7 (VM), R17.2, R31.1, U3.4 (-); also elsewhere on the board
VREG: U8.1 (V+), U8.20 (V+); also elsewhere on the board
iLIM0: R2.2; also elsewhere on the board
iLIM1: R10.2; also elsewhere on the board
iLIM2: R11.2; also elsewhere on the board
iLIM3: R36.2; also elsewhere on the board
iSENSE: U3.1; also elsewhere on the board
tSENSE: R37.1, R38.2; also elsewhere on the board

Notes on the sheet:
Current Sense to ADC
Voltage Regulator
H-Bridge
Temp to ADC
H-Bridge Power
DCC out
12..18V power
Booster
Gain: 20x
from DAC

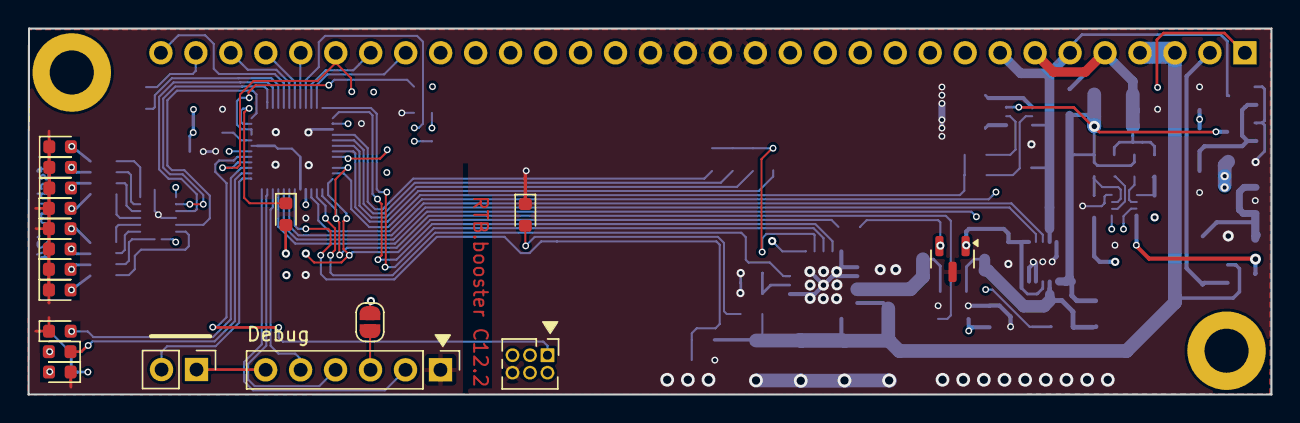
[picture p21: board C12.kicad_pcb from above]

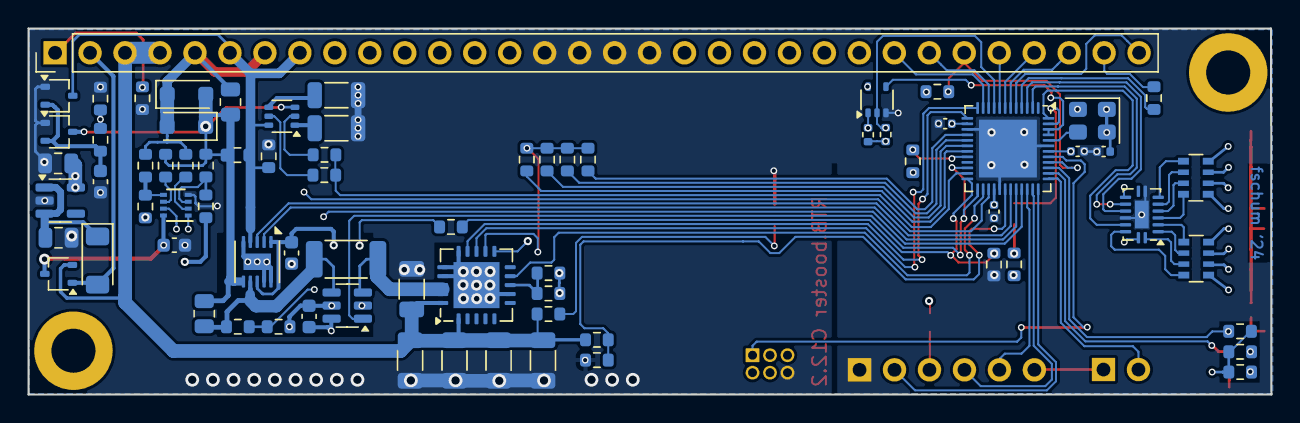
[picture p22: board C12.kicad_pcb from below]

Board: 4 copper layers, 90.3 x 26.6 mm, 94 parts (76 on the bottom side), 86 nets.

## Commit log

2025-09-02 mod: optimized for PCB assembly
    [C12.kicad_pcb, C12.sch, C12_2_bom.csv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]
2025-09-25 upgrade to Kicad 9
    [C12.kicad_pcb, C12.kicad_sch, C12.sch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]
2025-11-18 add: fuses document
2025-11-18 Add UPDI / Fuses section to README
    Added UPDI and fuse settings section to README.
